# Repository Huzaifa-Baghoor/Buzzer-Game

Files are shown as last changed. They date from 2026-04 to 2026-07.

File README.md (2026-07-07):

# Buzzer Game

This is a buzzer game setup like we see in TV shows, in which the player that presses the button first, his buzzer beeps and all other players are locked out until the admin allows.

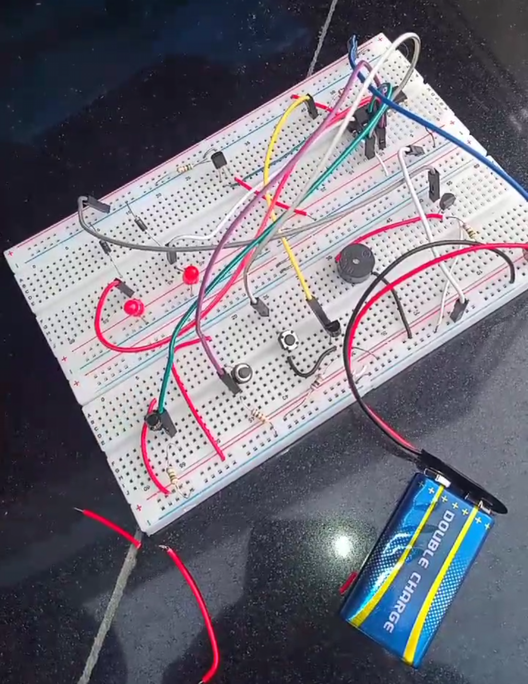
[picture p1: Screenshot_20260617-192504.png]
3D Model


## Working

The 74HC373 IC has an octal D-Latch that controls the first to press logic. The LE pin is controlled by a feedback loop. When a player presses his button the IC captures that state by pulling the LE pin low and freezes the mechanism and when the admin button is pressed it resets the latch.

## PCB

I made a PCB for this project, I tried to keep it single sided but there are two tracks that are on the bottom layer.

|Schematics|Tracks|
| :---: | :---: |
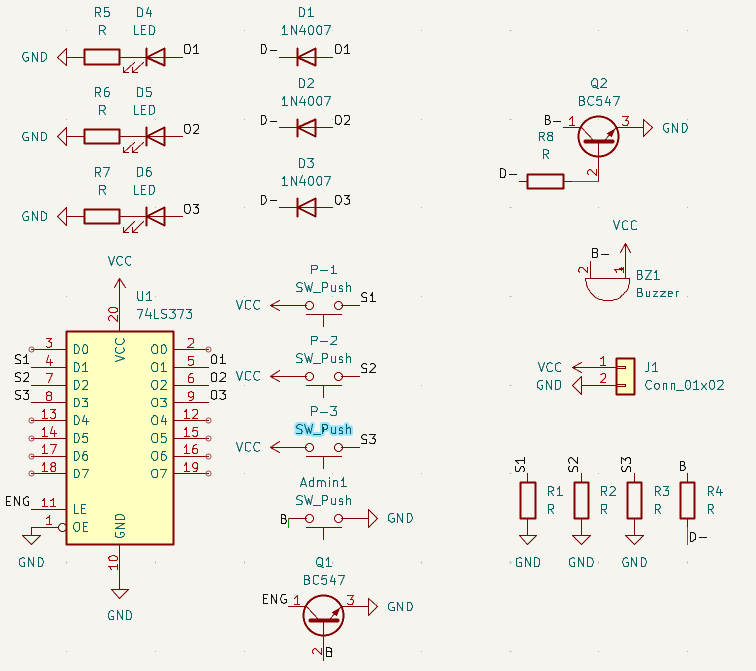
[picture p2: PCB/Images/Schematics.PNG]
schemetics
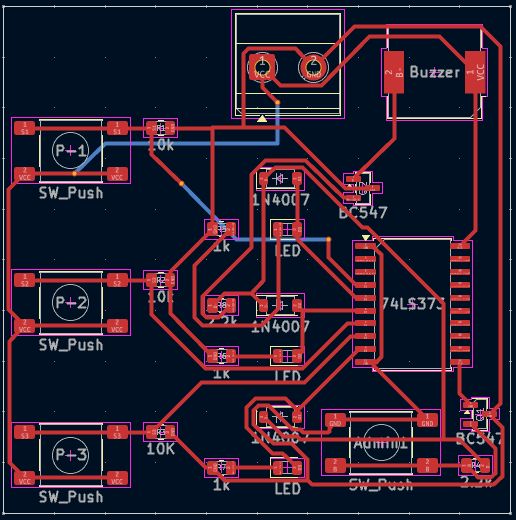
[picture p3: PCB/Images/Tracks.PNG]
Tracks
|  |  |

## 3D Casing

I also designed a 3D enclosure box for the Project.

|Box|Lid|
| :---: | :---: |
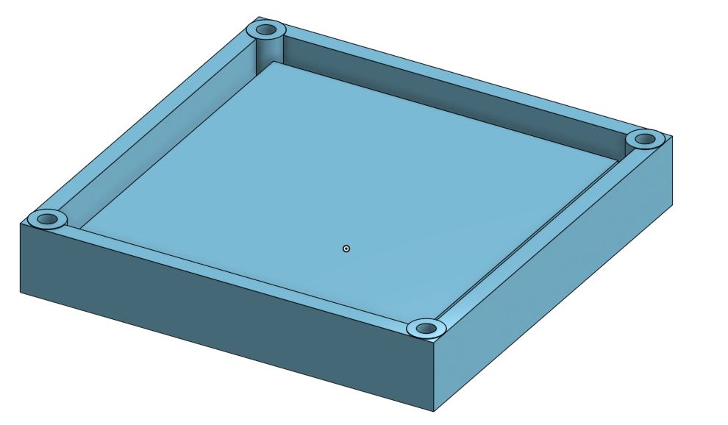
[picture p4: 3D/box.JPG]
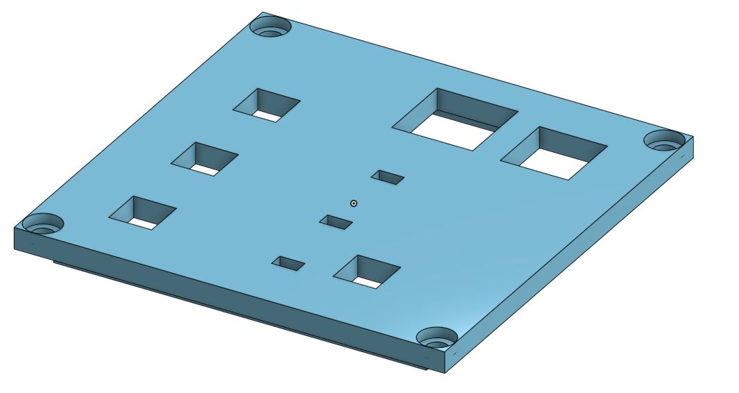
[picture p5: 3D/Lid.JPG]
Lid
|  |  |

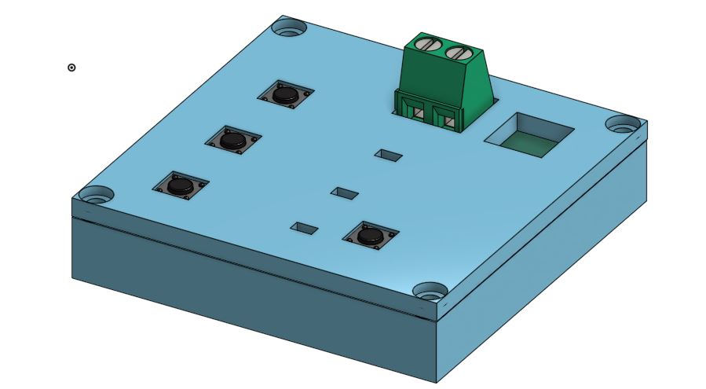
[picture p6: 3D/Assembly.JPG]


## Bill of Materials (BOM)

| Name | Quantity | Total Cost (USD) | Link | Distributor |
| :---: | :---: | :---: | :---: | :---: |
| Solder Mask | 1 | 1.65 | [Solder Mask](https://epro.pk/product/10cc-uv-solder-mask-ink-flux-welding-mechanic-in-pakistan/) | EPro |
| Ferric Chloride | 2 | 1.00 | [Ferric Chloride](https://epro.pk/product/ferric-chloride-powder-for-pcb-etchant-fecl-in-pakistan/) | EPro |
| Rivets | 1 | 9.00 | - | AliExpress |
| Transparency Sheets | 1 | 8.00 | [Transparency Sheets](https://stationers.pk/products/transparency-sheets?_pos=1&_sid=1455f1e48&_ss=r) | Stationers |
| Copper Clad Board | 1 | 7.00 | [Copper Clad Board](https://epro.pk/product/double-sided-pcb-12x12-in-pakistan/) | EPro |
| Reflow Gun | 1 | 15.00 | [Reflow Gun](https://digilog.pk/products/kada-835d-hot-air-gun-smd-rework-station-thermo-control-anti-static-portable-smd-rework-station) | DigiLog |
| Resistors | 11 | 4.86 | [Resistors](https://www.aliexpress.com/item/1005004145810949.html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) | AliExpress |
| Buzzer | 3 | 4.36 | [Buzzer](https://www.aliexpress.com/item/4000043951008.html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) | AliExpress |
| LEDs | 3 | 7.00 | [LEDs](https://www.aliexpress.com/item/1005009128722843.html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) | AliExpress |
| Button | 4 | 1.59 | [Button](https://www.aliexpress.com/item/1005001304127863.html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) | AliExpress |
| 1N4007 Diode | 3 | 2.38 | [Diode](https://www.aliexpress.com/item/32751841595.html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) | AliExpress |
| BC847 Transistor | 2 | 2.32 | [Transistor](https://www.aliexpress.com/item/1005008829335370.html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) | AliExpress |
| 74HC373 IC | 1 | 4.11 | [74HC373 IC](https://www.aliexpress.com/item/33052702425.html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) | AliExpress |

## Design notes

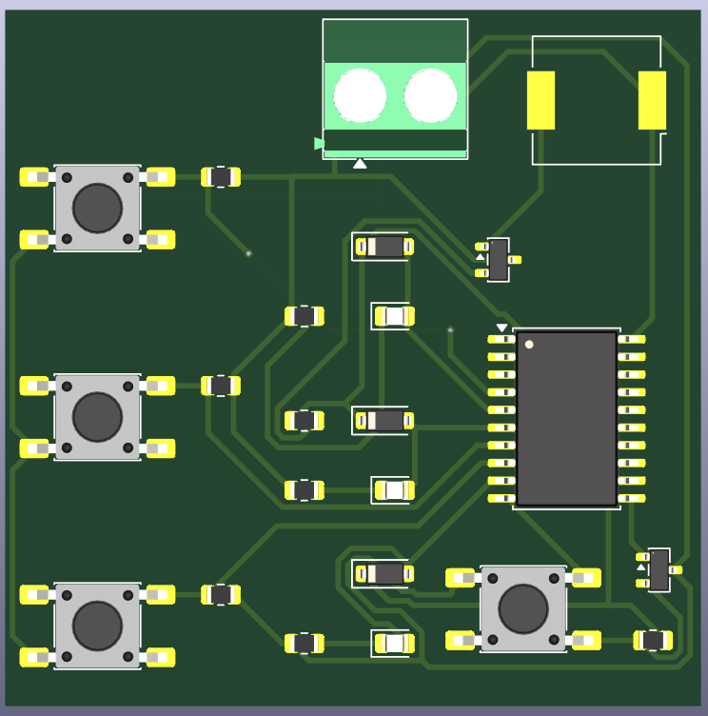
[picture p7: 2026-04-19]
PCB/Images/3D.PNG

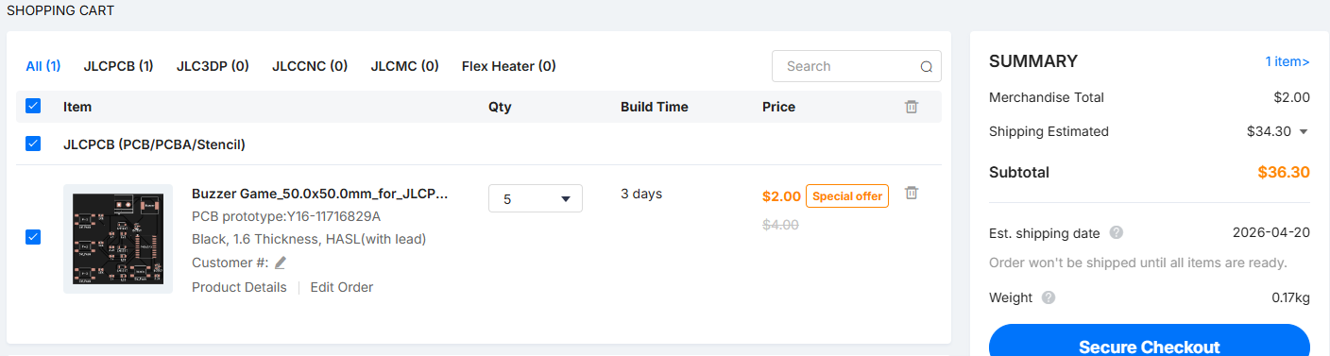
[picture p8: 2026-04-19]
PCB/Images/JLC.PNG

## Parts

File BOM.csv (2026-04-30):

Name | Purpose | Quantity | Total Cost (USD) | Link | Distributor
Solder Mask | For Pcb Making | 1 | 1.65 | https://epro.pk/product/10cc-uv-solder-mask-ink-flux-welding-mechanic-in-pakistan/ | EPro
Ferric Choloride | For PCB making | 2 | 1.00 | https://epro.pk/product/ferric-chloride-powder-for-pcb-etchant-fecl-in-pakistan/ | EPro
Rivets | For vias in PCB | 1 | 9.00 |  | Aliexpress
Transparency sheets | For PCB making | 1 | 8.00 | https://stationers.pk/products/transparency-sheets?_pos=1&_sid=1455f1e48&_ss=r | Stationers
Copper Clad Board | For PCB making | 1 | 7.00 | https://epro.pk/product/double-sided-pcb-12x12-in-pakistan/ | EPro
Reflow gun | For Soldering | 1 | 15.00 | https://digilog.pk/products/kada-835d-hot-air-gun-smd-rework-station-thermo-control-anti-static-portable-smd-rework-station | DigiLog
Resistors | 0805 SMD Resistor | 3 | 4.86 | https://www.aliexpress.com/item/1005004145810949.html?mp=1 | Ali Express
Buzzer | 9x9 Buzzer | 3 | 4.36 | https://www.aliexpress.com/item/4000043951008.html?mp=1 | Ali Express
Button | 6x6 push button | 3 | 1.59 | https://www.aliexpress.com/item/1005001304127863.html?mp=1 | Ali Express
Blue LED | 0805 LED | 1 | 2.21 | https://www.aliexpress.com/item/1005009128722843.html?mp=1 | Ali Express
Green LED | 0805 LED | 1 | 2.27 | https://www.aliexpress.com/item/1005009128722843.html?mp=1 | Ali Express
Red LED | 0805 LED | 1 | 2.26 | https://www.aliexpress.com/item/1005009128722843.html?mp=1 | Ali Express
1N4007 Diode | Diode | 3 | 2.32 | https://www.aliexpress.com/item/32751841595.html?mp=1 | AliExpress
BC 847 | Transistor | 2 | 2.37 | https://www.aliexpress.com/item/1005008829335370.html?mp=1 | Ali Express
74HC373 IC | Main IC for the buzzer game | 1 | 4.11 | https://www.aliexpress.com/item/33052702425.html?mp=1 | Ali Express

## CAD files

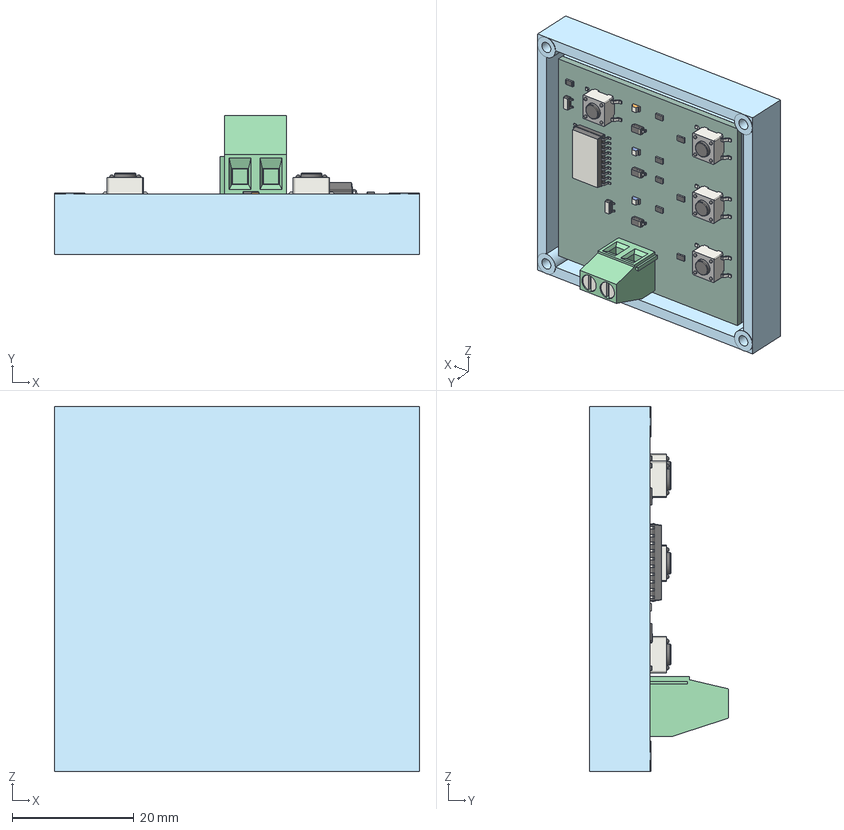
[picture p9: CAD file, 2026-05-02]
3D/Assembly.step
60.0 x 22.9 x 60.0 mm
R_0805_2012Metric_7
D_SOD-123_1
LED_0805_2012Metric_2
D_SOD-123
R_0805_2012Metric
TerminalBlock_Phoenix_MKDS-1,5-2-5.08_1x02_P5.08mm_Horizontal
R_0805_2012Metric_3
LED_0805_2012Metric_1
R_0805_2012Metric_2
SW_Push_1P1T_NO_E-Switch_TL3301NxxxxxG_1
Buzzer Game_PCB
R_0805_2012Metric_6
SW_Push_1P1T_NO_E-Switch_TL3301NxxxxxG
R_0805_2012Metric_4
D_SOD-123_2
SOIC-20W_7.5x12.8mm_P1.27mm
SW_Push_1P1T_NO_E-Switch_TL3301NxxxxxG_3
R_0805_2012Metric_5
SW_Push_1P1T_NO_E-Switch_TL3301NxxxxxG_2
R_0805_2012Metric_1
SOT-23
LED_0805_2012Metric
SOT-23_1

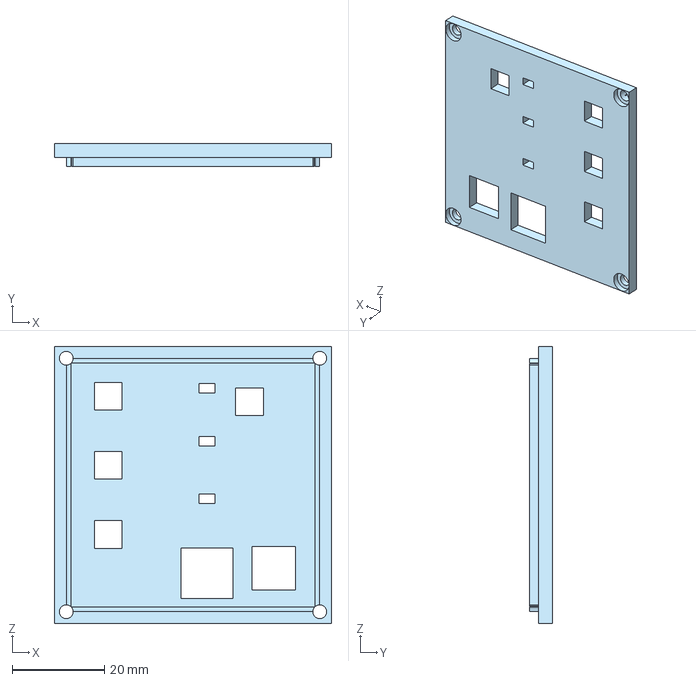
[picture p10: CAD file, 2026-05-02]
3D/Lid.step
60.1 x 5.00 x 60.1 mm

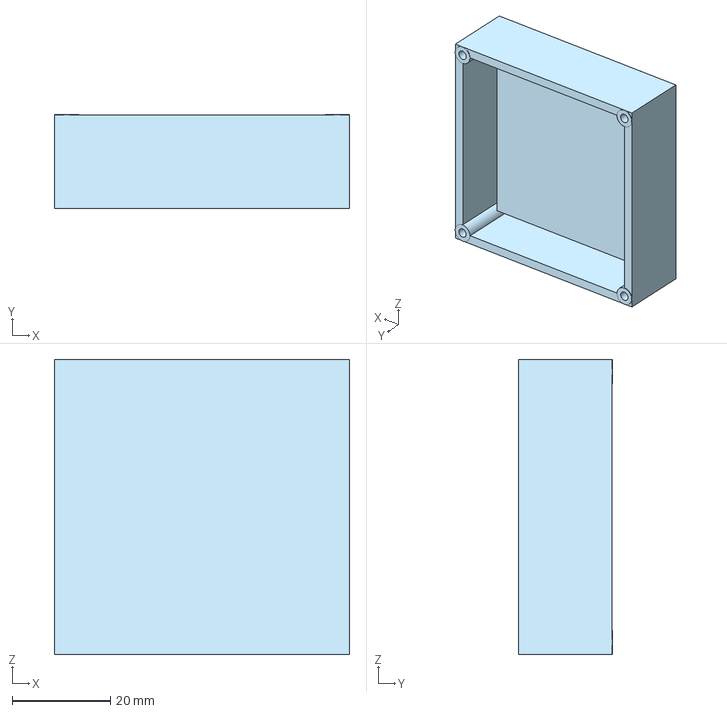
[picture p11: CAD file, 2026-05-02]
3D/Box.step
60.0 x 19.2 x 60.0 mm

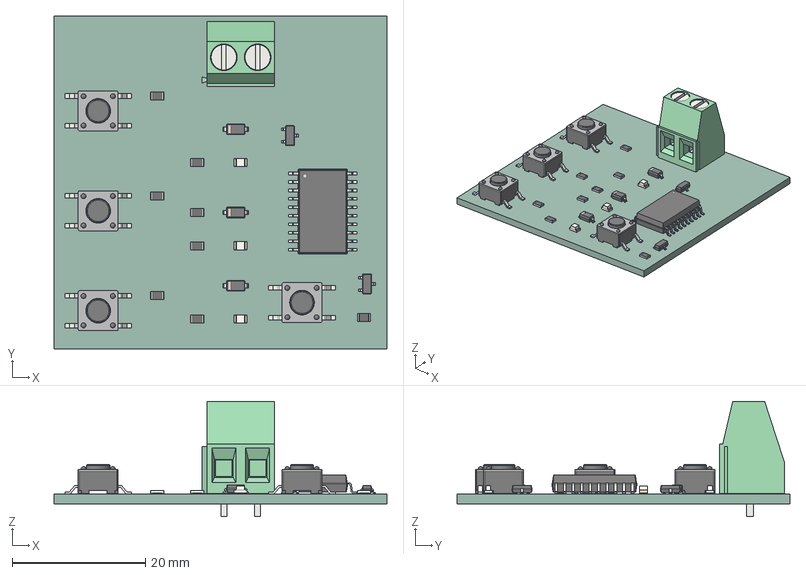
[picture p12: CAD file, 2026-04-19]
3D/Buzzer Game.step
50.0 x 50.0 x 17.3 mm
SOT-23 x 2
R_0805_2012Metric x 8
LED_0805_2012Metric x 3
SW_Push_1P1T_NO_E-Switch_TL3301NxxxxxG x 4
D_SOD-123 x 3
SOIC-20W_7.5x12.8mm_P1.27mm
TerminalBlock_Phoenix_MKDS-1,5-2-5.08_1x02_P5.08mm_Horizontal
Buzzer Game_PCB

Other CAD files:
3D/Buzzer Game.stl

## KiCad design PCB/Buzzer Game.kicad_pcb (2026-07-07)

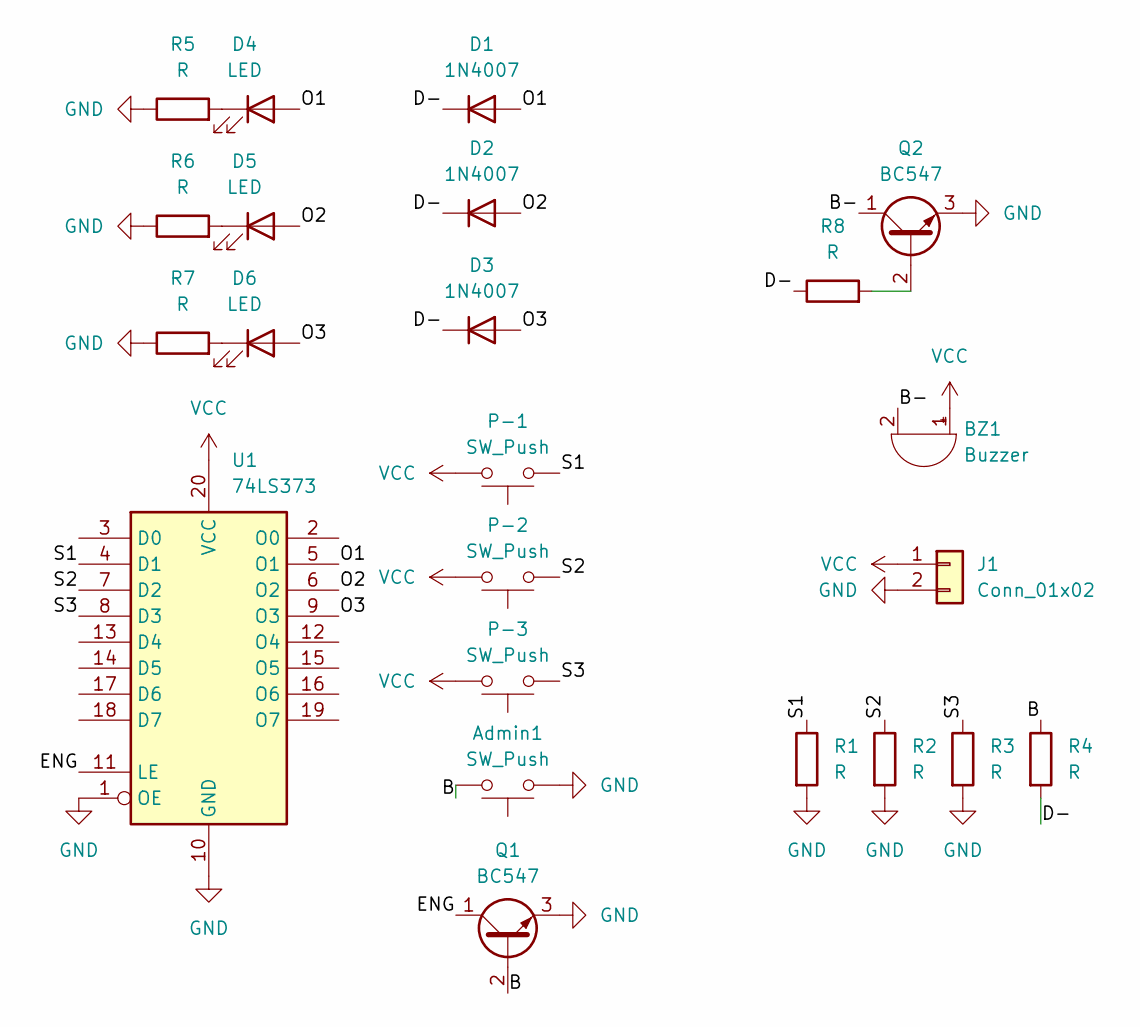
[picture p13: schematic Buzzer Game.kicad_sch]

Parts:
Admin1: SW_Push; SW_PUSH_6mm
BZ1: Buzzer; Buzzer_12x9.5RM7.6
D1, D2, D3: 1N4007; D_DO-41_SOD81_P10.16mm_Horizontal
D4, D5, D6: LED; LED_D5.0mm
J1: Conn_01x02; TerminalBlock_Phoenix_MKDS-1,5-2-5.08_1x02_P5.08mm_Horizont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
P-1, P-2, P-3: SW_Push; SW_PUSH_6mm
Q1, Q2: BC547; TO-92_Inline
R1, R2, R3, R4, R5, R6, R7, R8: R; R_Axial_DIN0207_L6.3mm_D2.5mm_P10.16mm_Horizontal
U1: 74LS373; DIP-20_W7.62mm_LongPads

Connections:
/B: Admin1.2, Q1.2 (B), R4.1
/B-: BZ1.2 (-), Q2.1 (C)
/D-: D1.1 (K), D2.1 (K), D3.1 (K), R4.2, R8.1
/ENG: Q1.1 (C), U1.11 (LE)
/O1: D1.2 (A), D4.2 (A), U1.5 (O1)
/O2: D2.2 (A), D5.2 (A), U1.6 (O2)
/O3: D3.2 (A), D6.2 (A), U1.9 (O3)
/S1: P-1.1, R1.1, U1.4 (D1)
/S2: P-2.1, R2.1, U1.7 (D2)
/S3: P-3.1, R3.1, U1.8 (D3)
GND: Admin1.1, J1.2, Q1.3 (E), Q2.3 (E), R1.2, R2.2, R3.2, R5.1, R6.1, R7.1, U1.1 (OE), U1.10 (GND)
unnamed: D4.1 (K), R5.2
unnamed: D5.1 (K), R6.2
unnamed: D6.1 (K), R7.2
unnamed: Q2.2 (B), R8.2
VCC: BZ1.1 (+), J1.1, P-1.2, P-2.2, P-3.2, U1.20 (VCC)

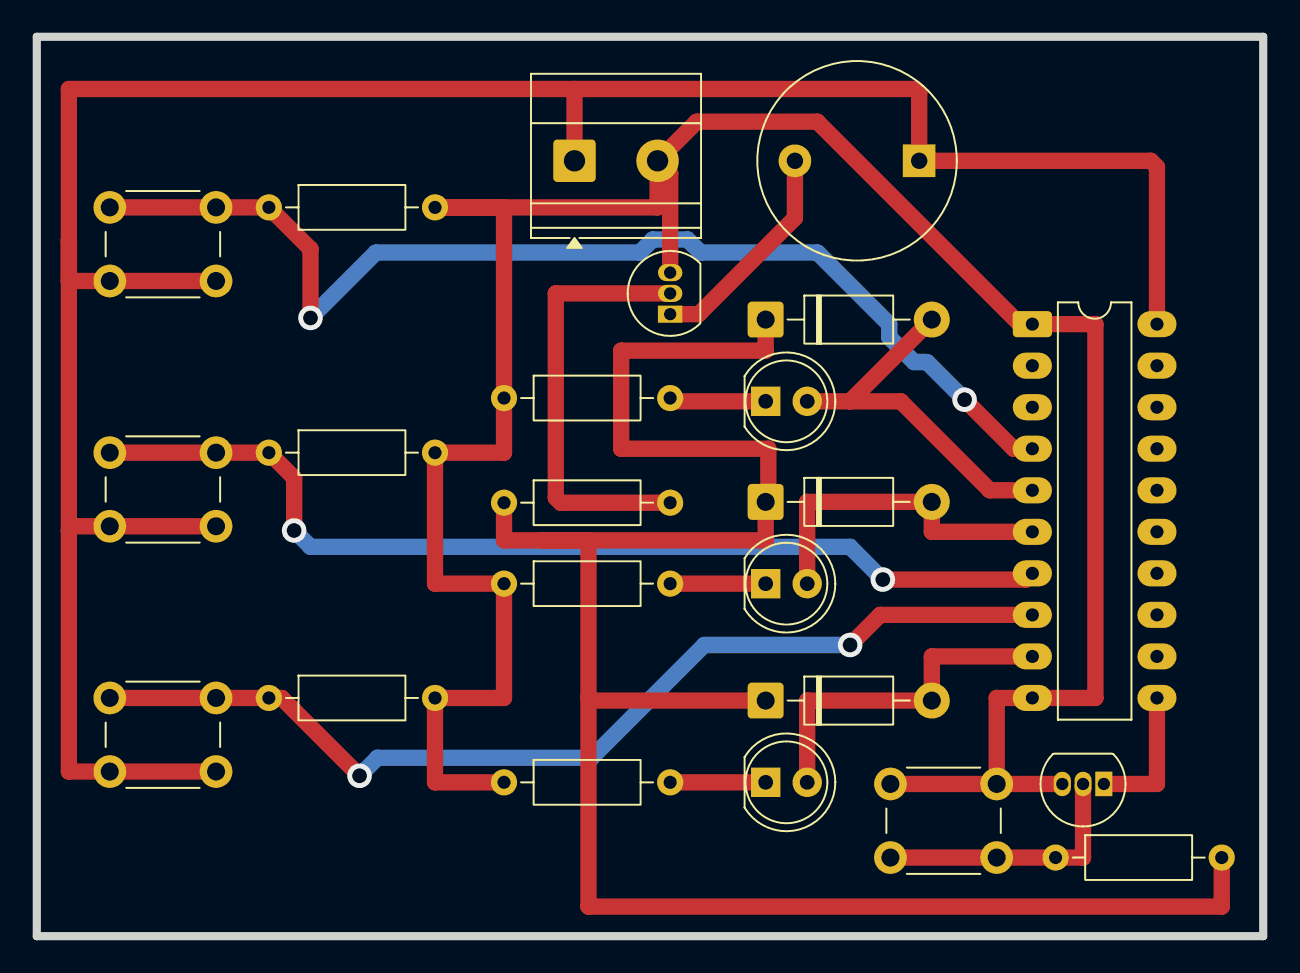
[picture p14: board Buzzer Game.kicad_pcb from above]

Board: 2 copper layers, 75.0 x 55.0 mm, 23 parts (0 on the bottom side), 16 nets.

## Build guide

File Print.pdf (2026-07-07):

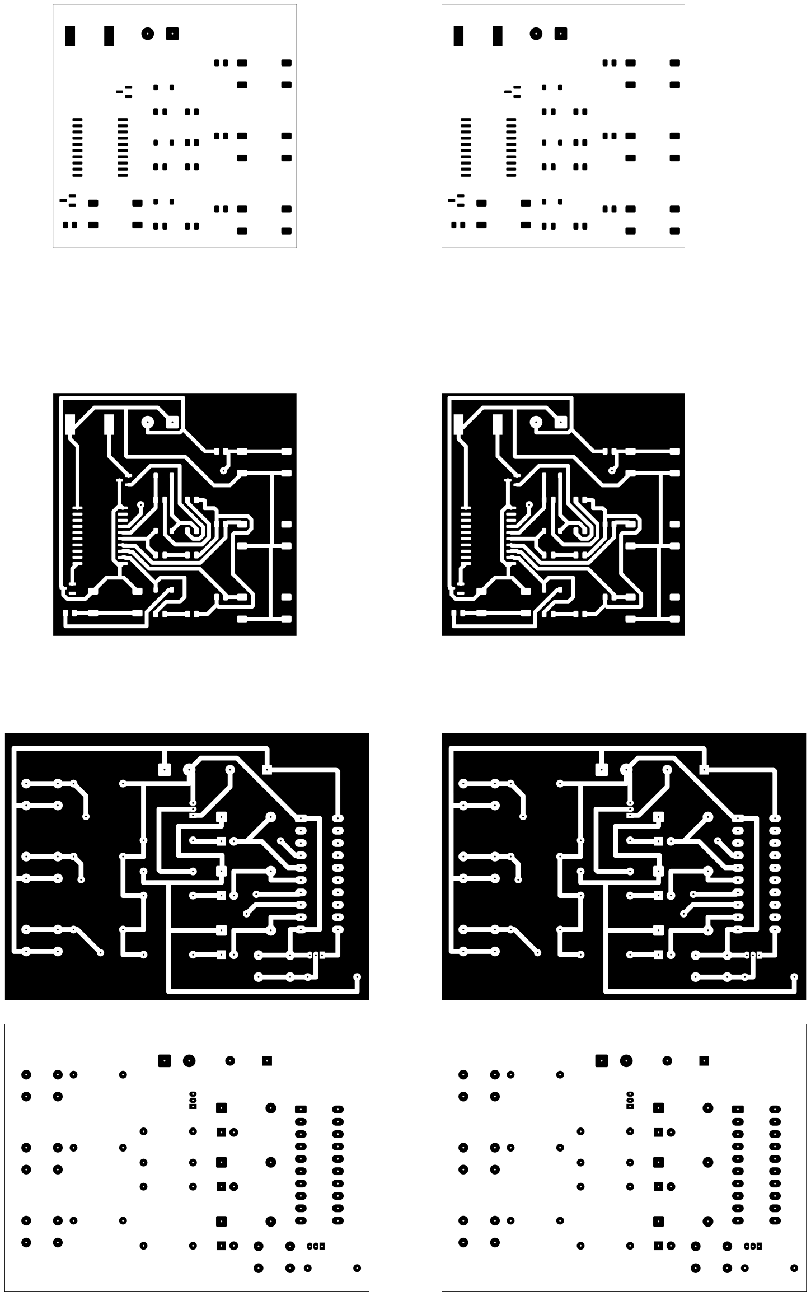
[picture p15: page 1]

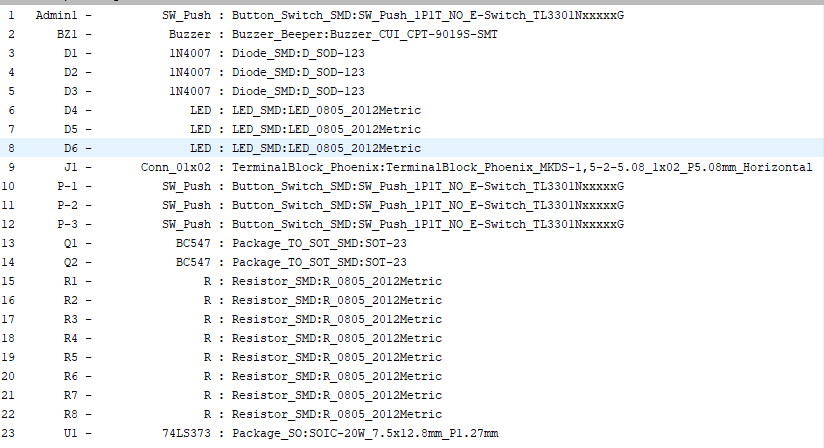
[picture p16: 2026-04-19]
PCB/Images/FootPrints.PNG

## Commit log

2026-04-19 PCB and 3D files
    [Buzzer Game.kicad_pcb, Buzzer Game.kicad_sch, Buzzer Game.step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]
2026-04-26 BOM added
    [BOM.csv]
2026-04-30 Updated README.md according to BOM.csv
2026-05-02 3D Assembly
    [Assembly.step, Box.step, Buzzer Game.step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]
